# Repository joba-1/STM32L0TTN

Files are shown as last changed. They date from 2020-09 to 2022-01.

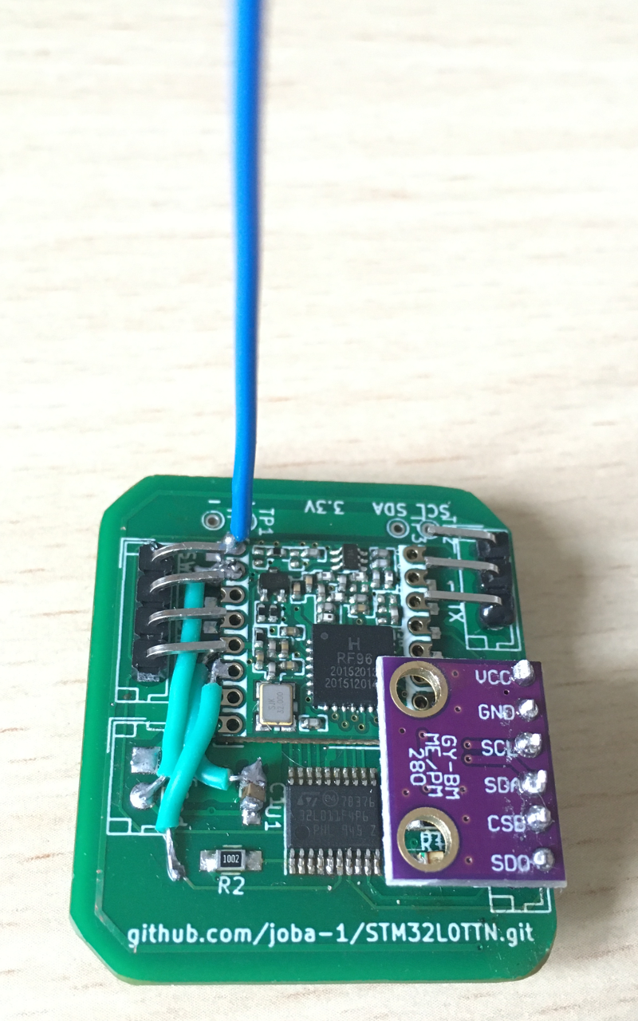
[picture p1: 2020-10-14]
kicad/wrong_rf95_and_cell_holder_footprint/thpl0-2-first-board.png

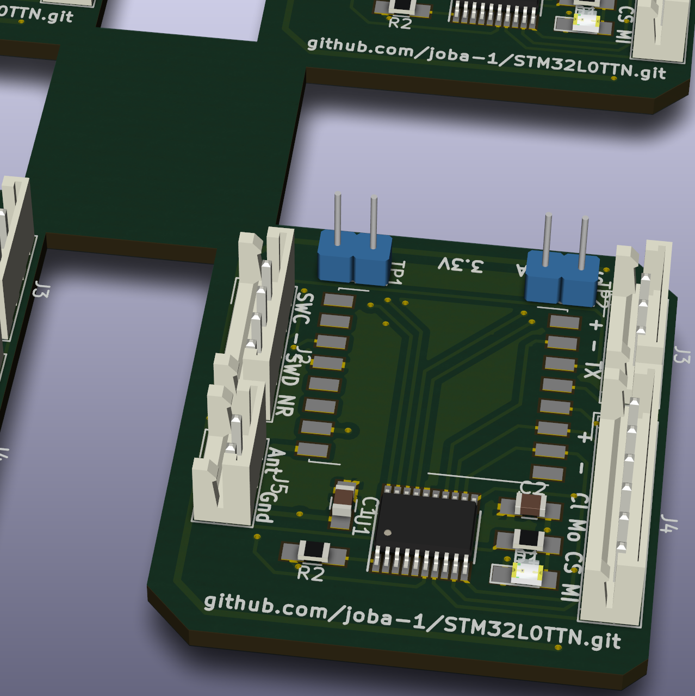
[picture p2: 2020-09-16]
kicad/4x4-buttoncell.png

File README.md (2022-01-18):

# STM32L0TTN

Send BME280 data and voltage to TTN with STM32L0

## Build

* Download and install STM32CubeIDE (as of now version 1.4.2)
* Import this repo
* Open .ioc file and select "Project/Generate Code" (should download needed "firmware" files for the chip from ST)
* Build Release or Debug (currently RAM 95%, FLASH 88% used)

## Wiring

connect Gnd of all components

### STM32L011

Not checked without, but generally recommended to use a small ceramic (~10nF) and big electrolyt condensator (~10µF) between + and - near STM pins



* Look at the ioc file with CubeMX pinout view.
* Vdd _and_ Vdda to 1.8-3.3V
* Vss to Gnd
* PB9-Boot0 pulled to Gnd (~10k) to safely boot from flash
* STLink for flashing and debug: SWD, SWC, Gnd, NRst (and could provide Vdd via JP1)

### BME280

* SDA=MOSI, SDC=MISO, others should be obvious

### RFM95W

* Ant=~8cm wire (vary length and position to get best average RSSI as reported by TTN)
* NSS=CS, others should be obvious (DIO0, DIO5, MOSI, MISO, SCK and RESET)

RFM95W pin labels for reuse of ESP32 adapter breadboard (print with 600dpi)


### Serial

Rx of a usb to serial converter sends at 115200. I use this command (serial port name ttyUSB_ser_red is defined in my /etc/udev/rules.d)
    pio device monitor -p /dev/ttyUSB_ser_red -b 115200

### LED

can be used without resistor. I use 1kOhm to save battery

## References

Good resource for STM32 is [Stefan Frings](http://stefanfrings.de/stm32/stm32l0.html)
He has links to reference, datasheet, errata and more. E.g.:

* [STM32L011 Datasheet](https://www.st.com/resource/en/datasheet/stm32l011d3.pdf)
* [STM32L011 Reference](https://www.st.com/resource/en/reference_manual/dm00108282-ultra-low-power-stm32l0x1-advanced-arm-based-32-bit-mcus-stmicroelectronics.pdf)
* [STM32L011 Errata](https://www.st.com/resource/en/errata_sheet/dm00237371-stm32l011x3-4-device-limitations-stmicroelectronics.pdf)
* [Power consumption](http://www.st.com/content/ccc/resource/technical/document/application_note/27/58/8e/81/79/fb/4f/ac/DM00108286.pdf/files/DM00108286.pdf/jcr:content/translations/en.DM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)

## Power Info Bits

* Examples for LL are here: STM32Cube/Repository/STM32Cube_FW_L0_V1.11.2/Projects/NUCLEO-L073RZ/Examples_LL/RTC/RTC_ExitStandbyWithWakeUpTimer
* Periodic wakeup timer is in Reference 22.4.6 (Periodic auto-wakeup)
* 1s to 18h periodic wakeup with ck_spre = 1s (see 22.4.3) and WUCKSEL [2:1] = 10
* Enable by WUTE bit in RTC_CR register
* Once setup it runs in normal and low power. 
* Sets WUTF flag in RTC_ISR if elapsed and reloads RTC_WUTR (timer counter). User resets WUTF
* Set WUTIE bit in RTC_CR to generate interrupt to wake up from low power modes
* System reset and Sleep, Stop, Standby have no influence on the WUT (wakeup timer)
* Save Lora frame counter in backup register: Reference 22.7.20 RTC backup registers (RTC_BKPxR)
* I couldnt make it work with LL lib, had to use big fat HAL for RCC and RTC. What is missing?

        LL_RTC_DisableWriteProtection(RTC);
        LL_RTC_WAKEUP_Disable(RTC);
        while( !LL_RTC_IsActiveFlag_WUTW(RTC) );
        LL_RTC_WAKEUP_SetClock(RTC, LL_RTC_WAKEUPCLOCK_CKSPRE);
        LL_RTC_WAKEUP_SetAutoReload(RTC, 3); // wake up every 3+1 s
        LL_RTC_EnableIT_WUT(RTC);
        LL_RTC_WAKEUP_Enable(RTC);
        LL_RTC_EnableWriteProtection(RTC);
        while( LL_RTC_IsActiveFlag_WUTW(RTC) );
        LL_RTC_ClearFlag_WUT(RTC);
        NVIC_ClearPendingIRQ(RTC_IRQn);

## Status

Works fine.
Power consumption much lower than with my similar ATTiny84 board

Bildschirmfoto von 2021-08-20 11-51-18

TTN migrated from V2 to V3. After they reactivated the device id ranges of the old network I could register the devices with the same devId, AppsKey and NwsKey.
After ~2 weeks the devices started showing up in the console -> code works unchanged with V3! Config example in this post: https://www.thethingsnetwork.org/forum/t/migrate-old-abp-device-to-v3

## Done
Not needed. by far the most power is consumed by sending. These tasks are not relevant
* Sleep while waiting for sensor or transmitter (90% of the ~100ms active cycle is waiting)
* Cut power of sensor and transmitter between measurements? Standby consumption is already quite low.
Works fine for a long time now. No problems so far
* Check recommended hookup of STM32L011K4 (capacitors, boot mode lines, reset, ...?). Since it works, it is probably ok as described above :)

## Todo
* PCBs for coin cell or 2xAAA: coin cell not at all good at low temp -> abandoned for BMP280 (outdoor) variants
* 3D-printed housings

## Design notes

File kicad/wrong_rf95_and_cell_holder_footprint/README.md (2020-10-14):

# First Prototype Board

## Good News

* It works and sends data
* It wasn't too hard to do the SMD soldering in my new oven (see my Reflowino project)

## Bad News

* The footprint of the RFM95 lib I used is wrong: the side with the antenna is the wrong direction
* The button cell clip works different from what I expected and was smaller
* The pcb antenna may be good for inhouse range but is not good enough for gateways some 5-10 km away 

So I had to cut some pcb traces and solder some wires. But in the end it worked and has a nice form factor!

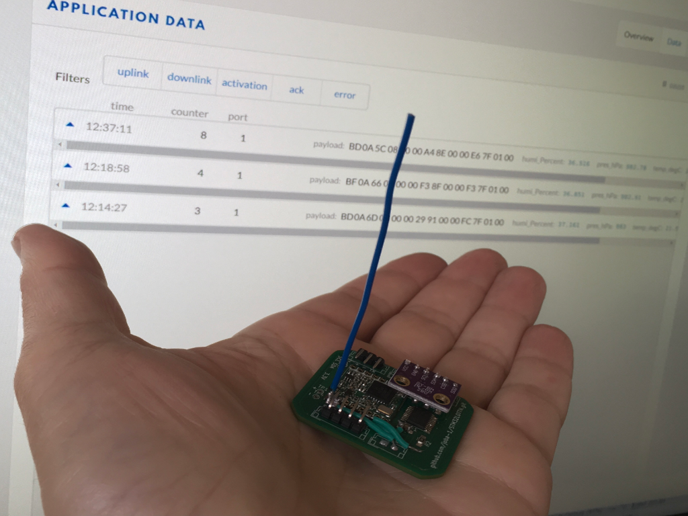
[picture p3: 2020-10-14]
kicad/wrong_rf95_and_cell_holder_footprint/thpl0-2-first-data.png

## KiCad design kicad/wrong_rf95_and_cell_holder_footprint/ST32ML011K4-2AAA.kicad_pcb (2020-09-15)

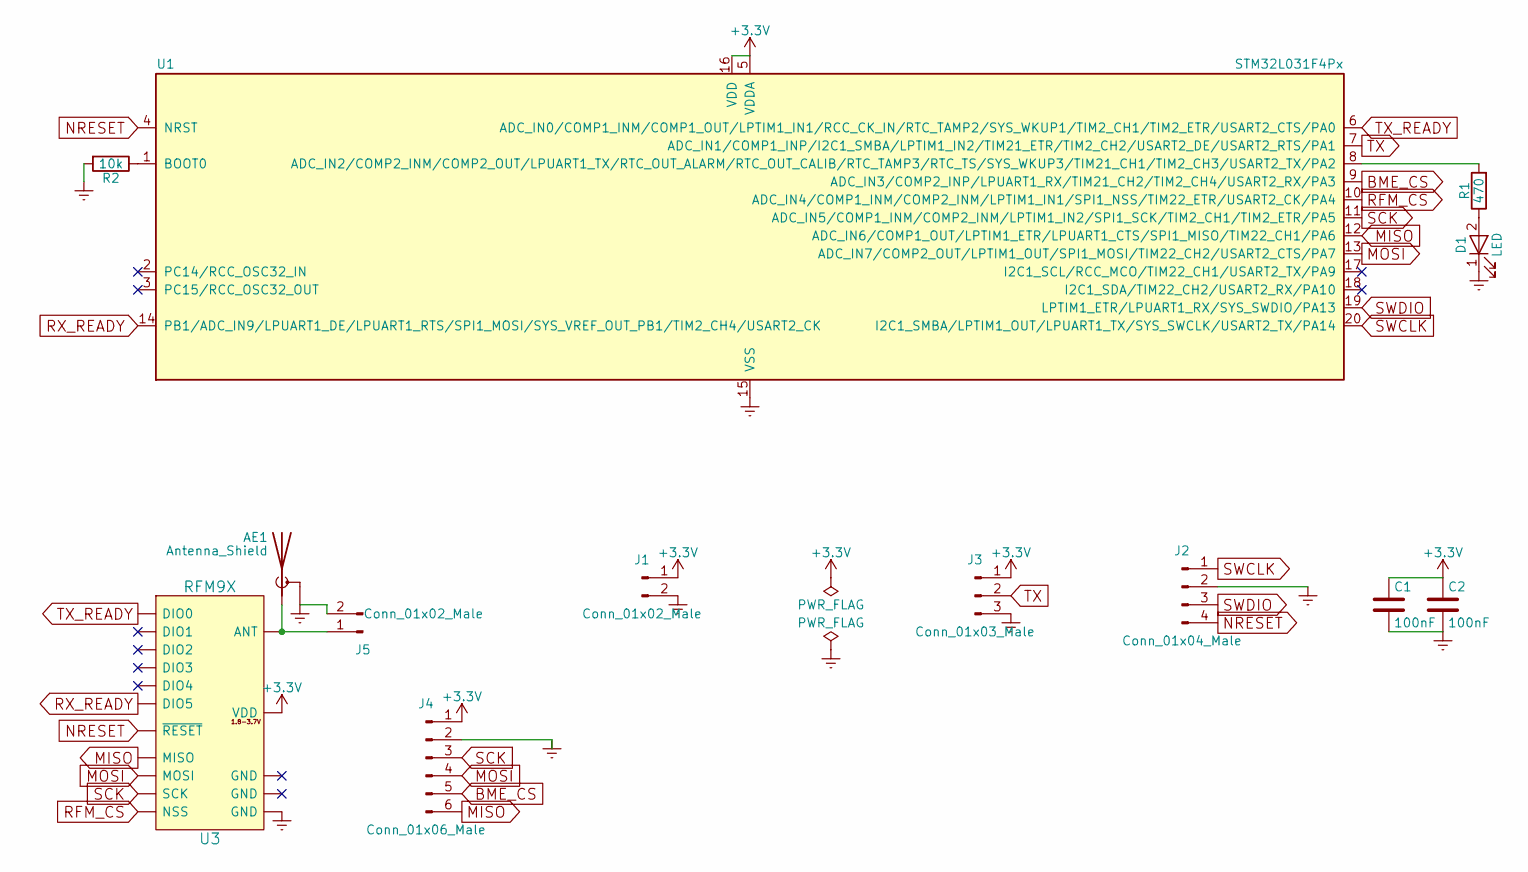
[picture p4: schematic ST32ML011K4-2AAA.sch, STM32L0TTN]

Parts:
AE1: Antenna_Shield; Pulse_W3011
C1, C2: 100nF; C_0805_HandSoldering
D1: LED; LED_0805_HandSoldering
J1: Conn_01x02_Male; Keystone_2468_2xAAA
J2: Conn_01x04_Male; JST_EH_B04B-EH-A_04x2.50mm_Straight
J3: Conn_01x03_Male; JST_EH_B03B-EH-A_03x2.50mm_Straight
J4: Conn_01x06_Male; JST_EH_B06B-EH-A_06x2.50mm_Straight
J5: Conn_01x02_Male; JST_EH_B02B-EH-A_02x2.50mm_Straight
R1: 470; R_0805_HandSoldering
R2: 10k; R_0805_HandSoldering
U1: STM32L031F4Px; TSSOP-20_4.4x6.5mm_Pitch0.65mm
U3: RFM9X; Hopref_RFM9XW_SMD

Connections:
+3V3: C1.1, C2.1, J1.1, J3.1, J4.1, U1.5 (VDDA), U1.16 (VDD), U3.12 (VDD)
BME_CS: J4.5, U1.9 (ADC_IN3/COMP2_INP/LPUART1_RX/TIM21_CH2/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)
Earth: AE1.2 (Shield), C1.2, C2.2, D1.1 (K), J1.2, J2.2, J3.3, J4.2, J5.2, R2.2, U1.15 (VSS), U3.15 (GND)
MISO: J4.6, U1.12 (ADC_IN6/COMP1_OUT/LPTIM1_ETR/LPUART1_CT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), U3.2 (MISO)
MOSI: J4.4, U1.13 (ADC_IN7/COMP2_OUT/LPTIM1_OUT/SPI1_MOSI/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), U3.3 (MOSI)
NRESET: J2.4, U1.4 (NRST), U3.6 (~RESET)
unnamed: AE1.1 (A), J5.1, U3.16 (ANT)
unnamed: D1.2 (A), R1.1
unnamed: R1.2, U1.8 (ADC_IN2/COMP2_INM/COMP2_OUT/LPUART1_TX/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)
unnamed: R2.1, U1.1 (BOOT0)
RFM_CS: U1.10 (ADC_IN4/COMP1_INM/COMP2_INM/LPTIM1_IN1/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), U3.5 (NSS)
RX_READY: U1.14 (PB1/ADC_IN9/LPUART1_DE/LPUART1_RTS/SPI1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), U3.7 (DIO5)
SCK: J4.3, U1.11 (ADC_IN5/COMP1_INM/COMP2_INM/LPTIM1_IN2/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), U3.4 (SCK)
SWCLK: J2.1, U1.20 (I2C1_SMBA/LPTIM1_OUT/LPUART1_TX/SYS_SWC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)
SWDIO: J2.3, U1.19 (LPTIM1_ETR/LPUART1_RX/SYS_SWDIO/PA13)
TX: J3.2, U1.7 (ADC_IN1/COMP1_INP/I2C1_SMBA/LPTIM1_IN2/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)
TX_READY: U1.6 (ADC_IN0/COMP1_INM/COMP1_OUT/LPTIM1_IN1/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), U3.11 (DIO0)

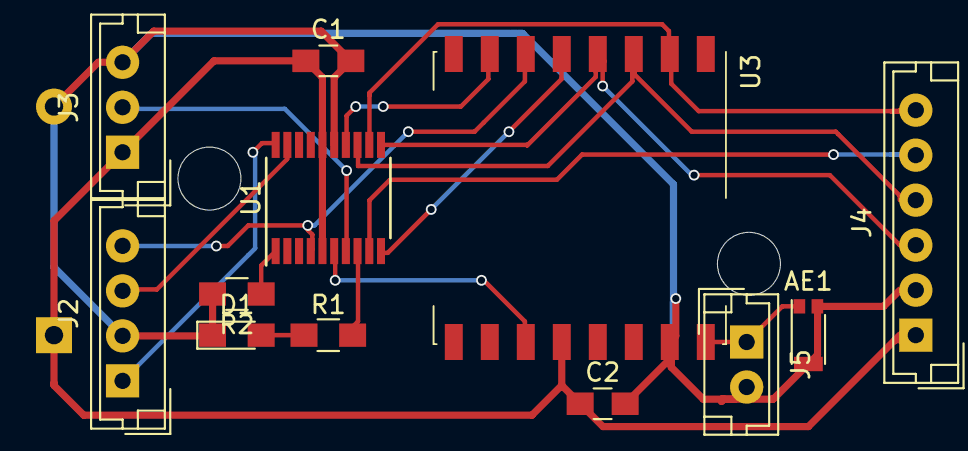
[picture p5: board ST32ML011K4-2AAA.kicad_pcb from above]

Board: 2 copper layers, 13 parts (1 on the bottom side), 17 nets.

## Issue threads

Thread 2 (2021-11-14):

How to set or find out DevEUI?

FursinMihail, 2021-11-14:
In the code I see only NwkSkey AppSkey and DevAddr. What should I do with DevEUI? I'm trying to transfer data to TTN.
Thank you in advance!

joba-1, 2021-11-14:
it is not needed for the ABP activation mode, only for devices using OTAA.

FursinMihail, 2021-11-15:
Yes it works thanks! There was a problem with the radio frequency and not the TTN configuration.

joba-1, 2021-11-15:
you‘re welcome. Thanks for reporting back.
May I ask if you actually used my code? Did you use it for the „new“ V3 TTN? I thought it might not work…

FursinMihail, 2021-11-16:
Yes, works with V3 TTN.
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

And the application server.
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

Can you tell me if I understand correctly that there is no mechanism for confirming the receipt of a message?

joba-1, 2021-11-16:
> Yes, works with V3 TTN.

Great news - I was afraid I have to dump my devices when they shut down V2 in 2 weeks.

> Can you tell me if I understand correctly that there is no mechanism for confirming the receipt of a message?

LoraWAN has this mechanism (downlinks) but my code has not.

I sacrificed it for space and power usage. An ATTiny84 and even more an STM32L011 has really low power usage. My devices run several months (ATTiny84) to well over a year and counting (STM32L011) without needing my attention. If you have to put the RFW95 in receiving mode for a while after each uplink that drains the power quite a bit. And for what? To adjust power levels and frequencies, requirements that pretty much never change (in my usecase). And so far I was not able to squeeze the code for that so that it fits in the 16kB that are available.

FursinMihail, 2021-11-16:
Got it, thanks. You can refuse hal and ll and there will be a lot of free space :) I don't like these libraries.

joba-1, 2021-11-16:
I agree regarding the HugeArmLib :D, but I wasnt really able to do without LL (ST docs and examples all use it, if not HAL) and it seems to be quite lean.

Reading chip reference manuals and understand all quirks necessary when using CMSIS so far was too much hassle for me as a ST/Arm beginner. Maybe you have some docs/resources that could make that easier?

FursinMihail, 2021-11-16:
The best source of knowledge about registers and peripherals for ST controllers is the reference manual: https://www.st.com/resource/en/reference_manual/rm0377-ultralowpower-stm32l0x1-advanced-armbased-32bit-mcus-stmicroelectronics.pdf

Take a look at the appendix A section for code examples.
Be prepared that different series of ST controllers have significant differences in working with the periphery. If you have any questions about working with CMSIS and ST microcontrollers, please contact. I can also recommend the Keil uVision environment, as for me it is very convenient (free version for non-commercial use with lemite firmware size 32kb).

Closed 2021-11-15.

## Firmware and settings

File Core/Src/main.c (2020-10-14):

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
/* Includes ------------------------------------------------------------------*/
#include "main.h"

/* USER CODE BEGIN Includes */

#include <bme280.h>
#include <rfm95.h>
#include <lorawan.h>
#include <secconfig.h>

/* USER CODE END Includes */

/* USER CODE BEGIN PTD */

typedef struct pins {
  GPIO_TypeDef *port;
  uint32_t     pin;
} pin_t;

/* USER CODE END PTD */

/* USER CODE BEGIN PD */

// no LED and no UART after this frame
#define QUIET_FRAME 10

/* USER CODE END PD */


RTC_HandleTypeDef hrtc;

/* USER CODE BEGIN PV */

// BME280 driver requires SPI read/write interface functions to use only one uint8 as device id.
// STM32 pins in LL libs are defined by port and pin so pin alone cannot be used as device id.
// To be able to reuse the same SPI functions for RFM and BME280, I use a dev -> port/pin mapping table
pin_t pins[] = {
  { BME_CS_GPIO_Port, BME_CS_Pin },
  { RFM_CS_GPIO_Port, RFM_CS_Pin },
  { RFM_D0_GPIO_Port, RFM_D0_Pin },
  { RFM_D5_GPIO_Port, RFM_D5_Pin }
};

// must correspond to array index above
typedef enum {
  BME280_CS_PIN_ID,
  RFM95_NSS_PIN_ID,
  RFM95_DIO0_PIN_ID,
  RFM95_DIO5_PIN_ID
} pin_id_t;

struct bme280_dev bme280_dev;
struct bme280_data bme280_data;
uint32_t bme280_delay;

rfm95_t rfm95_dev;
uint8_t rfm95_ver;
lorawan_t lorawan;
uint16_t frame_counter;

/* USER CODE END PV */

void SystemClock_Config(void);
static void MX_GPIO_Init(void);
static void MX_LPUART1_UART_Init(void);
static void MX_RTC_Init(void);
static void MX_SPI1_Init(void);
static void MX_ADC_Init(void);
/* USER CODE BEGIN 0 */

void putstr( const char *str ) {
  if( frame_counter > QUIET_FRAME )  return;
  LL_LPUART_Enable(LPUART1);
  while (*str) {
    while (!LL_LPUART_IsActiveFlag_TXE(LPUART1));
    LL_LPUART_TransmitData8(LPUART1, (uint8_t)*str++);
  }
  while (!LL_LPUART_IsActiveFlag_TC(LPUART1));
  LL_LPUART_Disable(LPUART1);
}


void putul( unsigned long u ) {
  if( frame_counter > QUIET_FRAME )  return;
  char num[11];
  char *d = &num[sizeof(num)-1];
  *d = '\0';
  if( u ) {
    while(u) {
      *(--d) = '0' + u % 10;
      u /= 10;
    }
  }
  else {
    *(--d) = '0';
  }
  putstr(d);
}


void puthex( uint8_t val ) {
  if( frame_counter > QUIET_FRAME )  return;
  static char hex[] = "0123456789abcdef";
  char msg[3];
  msg[0] = hex[val >> 4];
  msg[1] = hex[val & 0xf];
  msg[2] = '\0';
  putstr(msg);
}


int8_t duplexSpi(uint8_t dev, uint8_t addr, uint8_t *data, uint16_t len) {
  LL_SPI_Enable(SPI1);
  LL_GPIO_ResetOutputPin(pins[dev].port, pins[dev].pin);

  LL_SPI_TransmitData8(SPI1, addr);

  while (!LL_SPI_IsActiveFlag_RXNE(SPI1));   // wait for rx to finish
  LL_SPI_ReceiveData8(SPI1);                 // avoid overflow

  while (len--) {
    while (!LL_SPI_IsActiveFlag_TXE(SPI1));  // wait for tx to finish
    LL_SPI_TransmitData8(SPI1, *data);       // send data or generate clock for slave

    while (!LL_SPI_IsActiveFlag_RXNE(SPI1)); // wait for rx to finish
    *data = LL_SPI_ReceiveData8(SPI1);       // read receive result
    data++;
  }

  while (LL_SPI_IsActiveFlag_BSY(SPI1));
  LL_GPIO_SetOutputPin(pins[dev].port, pins[dev].pin);
  LL_SPI_Disable(SPI1);

  return 0;
}


uint8_t readPin(uint8_t dev) {
  return LL_GPIO_IsInputPinSet(pins[dev].port, pins[dev].pin);
}


uint8_t *serialize(uint8_t *data, uint32_t value, size_t size) {
  while( size-- ) {
    *(data++) = value & 0xff;
    value >>= 8;
  }
  return data;
}


uint16_t getVdda() {
  LL_ADC_Enable(ADC1);

  while( !LL_ADC_IsActiveFlag_ADRDY(ADC1) );
  LL_ADC_REG_StartConversion(ADC1);
  while( !LL_ADC_IsActiveFlag_EOC(ADC1) );

  uint16_t mV = LL_ADC_REG_ReadConversionData12(ADC1);
  mV = VREFINT_CAL_VREF * (*VREFINT_CAL_ADDR) / mV;

  while( !LL_ADC_IsActiveFlag_EOS(ADC1) );
  LL_ADC_Disable(ADC1);

  return mV;
}


void bme_setup() {
  bme280_dev.dev_id = BME280_CS_PIN_ID;
  bme280_dev.intf = BME280_SPI_INTF;
  bme280_dev.read = duplexSpi;
  bme280_dev.write = duplexSpi;
  bme280_dev.delay_ms = LL_mDelay;

  int bme_init = 0;

  while( !bme_init ) {
    if (bme280_init(&bme280_dev) == BME280_OK) {
      bme280_dev.settings.osr_h = BME280_OVERSAMPLING_1X;
      bme280_dev.settings.osr_p = BME280_OVERSAMPLING_16X;
      bme280_dev.settings.osr_t = BME280_OVERSAMPLING_2X;
      bme280_dev.settings.filter = BME280_FILTER_COEFF_16;
      if( bme280_set_sensor_settings(BME280_OSR_PRESS_SEL | BME280_OSR_TEMP_SEL | BME280_OSR_HUM_SEL | BME280_FILTER_SEL, &bme280_dev) == BME280_OK ) {
        bme280_delay = bme280_cal_meas_delay(&bme280_dev.settings);
        putstr(" BME delayMs:"); putul(bme280_delay);
        if( bme280_delay ) {
          bme_init = 1;
        }
      }
      else {
        putstr(" BME setup error!\n");
      }
    }
    else {
      putstr(" BME init error!\n");
    }

    if( ! bme_init ) {
      LL_mDelay(1000);
    }
  }
}


int bme_read() {
  bme280_data.humidity = 0;
  if( bme280_set_sensor_mode(BME280_FORCED_MODE, &bme280_dev) == BME280_OK ) {
    bme280_dev.delay_ms(bme280_delay);
    bme280_get_sensor_data(BME280_ALL, &bme280_data, &bme280_dev);
  }

  return bme280_data.humidity >         0 && bme280_data.humidity  <= 100000
      && bme280_data.pressure >     81000 && bme280_data.pressure  <  110000
      && bme280_data.temperature > -50000 && bme280_data.temperature <= 9500;
}


void bme_print() {
  putstr(" T:");      putul(bme280_data.temperature);
  putstr(" c°C, H:"); putul(bme280_data.humidity);
  putstr(" m%, P:");  putul(bme280_data.pressure);
  putstr(" Pa");
}


void rfm_setup( uint32_t seed ) {
  rfm95_dev.nss_pin_id = RFM95_NSS_PIN_ID;
  rfm95_dev.dio0_pin_id = RFM95_DIO0_PIN_ID;
  rfm95_dev.dio5_pin_id = RFM95_DIO5_PIN_ID;
  rfm95_dev.spi_write = duplexSpi;
  rfm95_dev.spi_read = duplexSpi;
  rfm95_dev.delay = LL_mDelay;
  rfm95_dev.pin_read = readPin;

  while( rfm95_ver != 0x12 ) {
    rfm95_ver = rfm95_init(&rfm95_dev, seed);
  }

  lorawan_init(&lorawan, &rfm95_dev);
  lorawan_set_keys(&lorawan, NwkSkey, AppSkey, DevAddr);

  // Print test package
  if( 0 ) {
      uint8_t buf[8];
      for( size_t i=0; i<sizeof(buf); i++ ) {
        buf[i] = i;
      }

    lorawan_send_data(&lorawan, buf, sizeof(buf), 0);
  }
}

/* USER CODE END 0 */

/**
  * @brief  The application entry point.
  * @retval int
  */
int main(void)
{
  /* MCU Configuration--------------------------------------------------------*/

  /* Reset of all peripherals, Initializes the Flash interface and the Systick. */
  HAL_Init();

  /* Configure the system clock */
  SystemClock_Config();

  /* Initialize all configured peripherals */
  MX_GPIO_Init();
  MX_LPUART1_UART_Init();
  MX_RTC_Init();
  MX_SPI1_Init();
  MX_ADC_Init();
  /* USER CODE BEGIN 2 */

  LL_GPIO_SetOutputPin(pins[BME280_CS_PIN_ID].port, pins[BME280_CS_PIN_ID].pin);
  LL_GPIO_SetOutputPin(pins[RFM95_NSS_PIN_ID].port, pins[RFM95_NSS_PIN_ID].pin);

  frame_counter = (uint16_t)HAL_RTCEx_BKUPRead(&hrtc, RTC_BKP_DR0);

  // After a few standby cycles don't waste power on led
  if( frame_counter <= QUIET_FRAME ) {
    LL_GPIO_SetOutputPin(LED_GPIO_Port, LED_Pin);
  }

  putstr("\nStart ST32ML0TTN 1.2 " __DATE__ " " __TIME__ " device 0x");
  for( unsigned i = 0; i < 4; i++ ) {
    puthex(DevAddr[i]);
  }

  if(__HAL_PWR_GET_FLAG(PWR_FLAG_SB) != RESET) {
    putstr(" from standby");
    __HAL_PWR_CLEAR_FLAG(PWR_FLAG_SB);
  }
  else {
    putstr(" from reset");
    // At first power on give a button cell a bit of time
    // to charge a capacitor before sending something to prevent boot loop
    LL_mDelay(5000);
  }

  rfm_setup(frame_counter);
  bme_setup();

  /* USER CODE END 2 */

  /* Infinite loop */
  /* USER CODE BEGIN WHILE */
  while (1)
  {
    putstr(" standbys:"); putul(frame_counter);

    if( bme_read() ) {
      bme_print();

      uint16_t mV = getVdda();
      putstr(" mV:"); putul(mV);

      uint8_t Data[sizeof(bme280_data)+sizeof(mV)];
      uint8_t *data = Data;
      data = serialize(data, mV, sizeof(mV));
      data = serialize(data, (uint32_t)bme280_data.temperature, sizeof(bme280_data.temperature));
      data = serialize(data, bme280_data.humidity, sizeof(bme280_data.humidity));
      serialize(data, bme280_data.pressure, sizeof(bme280_data.pressure));

      putstr(" send ");
      putul(lorawan_send_data(&lorawan, Data, sizeof(Data), frame_counter)/1000);
      putstr(" kHz");
    }

    LL_GPIO_ResetOutputPin(LED_GPIO_Port, LED_Pin);

    if( frame_counter == QUIET_FRAME ) {
      putstr(" continue quietly\n");
    }

    HAL_RTCEx_BKUPWrite(&hrtc, RTC_BKP_DR0, ++frame_counter);

    putstr(" wake:"); putul(INTERVAL_S); putstr(" s");

    HAL_PWREx_EnableUltraLowPower();
    HAL_PWREx_EnableFastWakeUp();
    __HAL_PWR_CLEAR_FLAG(PWR_FLAG_WU);
    HAL_PWR_EnterSTANDBYMode();

    putstr(" STANDBY ERROR\n");

    LL_mDelay(60000);

    HAL_DeInit();
    NVIC_SystemReset();

    /* USER CODE END WHILE */

    /* USER CODE BEGIN 3 */
  }
  /* USER CODE END 3 */
}

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


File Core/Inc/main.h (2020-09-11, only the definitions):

#define INTERVAL_S 300
#define RFM_D0_Pin LL_GPIO_PIN_0
#define RFM_D0_GPIO_Port GPIOA
#define LED_Pin LL_GPIO_PIN_2
#define LED_GPIO_Port GPIOA
#define BME_CS_Pin LL_GPIO_PIN_3
#define BME_CS_GPIO_Port GPIOA
#define RFM_CS_Pin LL_GPIO_PIN_4
#define RFM_CS_GPIO_Port GPIOA
#define RFM_D5_Pin LL_GPIO_PIN_1
#define RFM_D5_GPIO_Port GPIOB

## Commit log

2020-09-10 switch gpio, lpuart, adc and spi to LL, add bme280
2020-09-10 set all CS high before using SPI
2020-09-11 quiet after 10th frame, 2 -> 1 MHz clock
2020-09-11 Add current ram and flash size
2020-09-11 settle adc: use after bme, print standby time and version
2020-09-11 condensator capacity can be smaller
2020-09-15 PCB for 2xAAA and 2032 button cell
    [ST32ML011K4-2AAA.kicad_pcb, ST32ML011K4-2AAA.sch, ST32ML011K4-Button.kicad_pcb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]
2020-09-16 gerber files V1 as sent to pcbway
    [4x4-buttoncell-B.Cu.gbl, 4x4-buttoncell-B.Mask.gbs, 4x4-buttoncell-B.SilkS.gbo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]
2020-09-16 undo autosave edits for 4x...
    [ST32ML011K4-Button.kicad_pcb]
2020-09-16 add 3d view of pcb
2020-10-14 now that prototype works: obsolete pcb files - need rework
    [4x4-buttoncell-B.Cu.gbl, 4x4-buttoncell-B.Mask.gbs, 4x4-buttoncell-B.SilkS.gbo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]
2021-08-26 Add STM32 TSSOP20 pinout to readme
2021-08-26 Add RFM95W pin labels to readme

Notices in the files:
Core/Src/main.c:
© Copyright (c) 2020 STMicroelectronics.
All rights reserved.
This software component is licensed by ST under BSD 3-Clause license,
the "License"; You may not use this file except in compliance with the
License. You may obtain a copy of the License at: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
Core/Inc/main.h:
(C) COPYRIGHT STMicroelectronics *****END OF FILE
